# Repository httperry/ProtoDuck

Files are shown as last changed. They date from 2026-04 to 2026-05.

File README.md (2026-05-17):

# ProtoDuck





ProtoDuck is a general use microcontroller designed by combining two separate chips (`RP2350B` & `ESP32-C6`) to provide the maximum potential to the microcontroller. The board was designed to solve these problems faced by other microcontrollers in the market:
1. Little to no circuit protection (Try accidentally touching a few pins using jumper wires0
2. Less GPIO pins (For ___some___ use cases)
3. Less wireless connectivity
4. Lack of libraries in software

The aim of ProtoDuck is to provide a safe baseline for tinkerers to be able to safely continue their journey in hardware

Please note that this is the first PCB I ever designed and may contain many flaws, you are free to point them out via the issues section and if possible I will try fixing them!

## Board Visuals

**3D Visualisation Front**

Screenshot 2026-05-04 at 10 08 20 PM

**3D Visualisation Back**

Screenshot 2026-05-17 at 11 40 32 AM

**Schematic Drawing**

Schematic_ProtoDuck_v1_2026-05-04

**Top Layer PCB**

Screenshot 2026-05-17 at 11 20 19 AM

**Bottom Layer PCB**

Screenshot 2026-05-17 at 11 20 46 AM

**Middle Layer PCB**

Screenshot 2026-05-17 at 11 21 07 AM

## System Architechture

The ProtoDuck runs on a dual-microcontroller setup to prevent bottlenecking:

* **Primary Chip (RP2350B):** The main brain. Handles PC communication, GPIO pins, and runs user code. One ARM core is dedicated purely to system tasks and ESP communication, while the remaining cores are fully available for user code.
* **Wireless Co-Processor (ESP32-C6):** Connected via RX/TX. Exclusively handles WiFi (2.4GHz), Bluetooth 5+, and Zigbee. A custom HAL is being developed so users can access wireless features without eating into their own processing overhead.

## Power & Protection

The power circuit is designed while keeping the MCUs in mind to prevent any load on them. It features a `CH224K` chip for proper USB Type-C power negotiation, an `SRV05-4-P-T7` TVS Diode to absorb static shocks on data lines, and a `TPS54302DDCR_C311983` Step-Down Converter to cleanly drop the negotiated voltage to a stable 3.3V.

> [!NOTE]  
> **Hardware eFuse (`TPS259271DRCR`)**
> The board features an eFuse that automatically trips upon overloading or overdrawing. When tripped, a bright LED illuminates and power is cut off from the rest of the board. To clear the fault, you must physically unplug and replug the cable.

## Data Storage

To maximize security and prevent corruption, memory is isolated into three separate 128Mbit Flash chips (`GD25Q128ESIGR`), alongside the ESP32-C6's internal flash:

1. **`USR_FC` (User Chip):** Stores user code. Lowest priority at boot. Only accessible via PC/GUI for updates.
2. **`RP_FC` (Firmware Chip):** Stores the bootloader, kernel, and HALs. Connected via QSPI to the RP2350B. Uses an A/B partition system (similar to Android OTA updates) for safe flashing.
3. **`BC_FC` (Backup Chip):** Contains compressed firmware and an emergency bootloader for both MCUs in case of total system corruption.

There are physical pins on board that allow the user to flash the chips in case of recovery

## Pinout & Peripherals

The board maximizes usable IO and includes onboard peripherals (Reset Button, User Flash Button, System Status LED, Buzzer) for quick testing.
| Type | Count | Pins | Details |
|---|---|---|---|
| **Digital** | 21 | `D0`-`D20` | Programmable for PWM, I2C, SPI, etc. |
| **Analog** | 8 | `A0`-`A7` | Standard ADC inputs |
| **VBUS Protected** | 3 | `VBUS_PROT` | Safely routed from USB |
| **3.3V Power** | 5 | `+3.3V` | Regulated output |
| **GND** | 9 | `GND` | System ground |
| **I2C Header** | 1 | `I2C` | Dedicated plug-and-play header for displays |
| **Debug Header** | 1 | Labeled on Board | SWCLK & SWDIO |

## Emergency Recovery

If the software fails completely, ProtoDuck has physical hardware pins dedicated to recovering the board. Shorting these 1x1 male pin headers to `GND` triggers the following:

> [!IMPORTANT]  
> **`SYS-R` (System Restore)**
> Automatically fetches the compressed firmware from the `BC_FC` backup chip and safely reflashes the primary `RP_FC` chip.

> [!CAUTION]  
> **`FW-FLS` (Firmware Flash)**
> The nuclear option. If `SYS-R` fails, shorting this pin forces the RP flash chip to mount as a mass storage device on your PC. You can then drag-and-drop the firmware files to manually recover.

## Project Files & Links

This project was built using EasyEDA. The `.json` project files are included in this repository. 

## Bill of Materials (BOM)
[BOM](https://raw.githubusercontent.com/httperry/ProtoDuck/refs/heads/main/BOM.csv)

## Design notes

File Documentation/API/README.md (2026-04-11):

# ProtoDuck API Reference

Welcome to the ProtoDuck API documentation. This reference covers every module available to user code running on the ProtoDuck microcontroller.

---

## Quick Start

```python
# Pins just work — no import needed
D1.write(HIGH)
A0.read()
bus = I2C(D3, D4)

# Import modules as you need them
from protoduck import wifi, led, buzzer

wifi.connect()
resp = wifi.get("https://api.example.com/data")
print(resp.json())

# Async main auto-runs — no boilerplate
async def main():
    while True:
        led.set(A0.map(0, 255), 0, 0)
        await asyncio.sleep_ms(100)
```

---

## Always-Available Globals

These are injected by `boot.py` automatically. **Never import them.**

| Name | Type | Description |
|---|---|---|
| `D0` – `D20` | Pin objects | Digital GPIO pins |
| `A0` – `A7` | Pin objects | Analog GPIO pins (ADC) |
| `HIGH` | `1` | Digital high (3.3V) |
| `LOW` | `0` | Digital low (0V) |
| `INPUT` | const | Pin direction: input |
| `OUTPUT` | const | Pin direction: output |
| `PULLUP` | const | Enable internal pull-up resistor |
| `PULLDOWN` | const | Enable internal pull-down resistor |
| `I2C()` | constructor | Create I2C bus |
| `SPI()` | constructor | Create SPI bus |
| `PWM()` | constructor | Create PWM output |
| `UART()` | constructor | Create UART port |
| `asyncio` | module | Pre-imported async library |

---

## Modules

Each module has its own detailed documentation page:

| Module | Import | Description |
|---|---|---|
| [GPIO](gpio.md) | *(no import needed)* | Pin I/O, ADC, I2C, SPI, PWM, UART |
| [WiFi](wifi.md) | `from protoduck import wifi` | WiFi connection, HTTP, WebSocket, MQTT, sockets, hotspot |
| [Bluetooth](bluetooth.md) | `from protoduck import bluetooth` | BLE scanning, connecting, advertising, GATT server |
| [Zigbee](zigbee.md) | `from protoduck import zigbee` | IEEE 802.15.4 mesh networking |
| [LED](led.md) | `from protoduck import led` | Onboard RGB status LED control |
| [Buzzer](buzzer.md) | `from protoduck import buzzer` | Onboard buzzer/tone control |
| [System](system.md) | `from protoduck import system` | Board info, memory, storage, reset |
| [Thread](thread.md) | `from protoduck import thread` | True parallel execution via FreeRTOS tasks |
| [PCH Bridge](pch.md) | `import pch` or `import pchost` | Run PC-side Python libraries from board code |

---

## Important Notes

- **Pin objects are true globals.** All pins (`D0`–`D20`, `A0`–`A7`), peripherals, and constants (`HIGH`, `LOW`, etc.) are natively available in your script's global scope. You never need to import them or use a prefix.
- **`async def main()` auto-runs.** If your script defines an async `main()` function, the system calls `asyncio.run(main())` for you automatically.
- **RST button = soft reset.** It restarts your Python code only. WiFi, BLE, and USB connections stay alive.
- **MicroPython ≠ CPython.** This is MicroPython 1.24+ (Python 3.4+ syntax). For full CPython libraries, use the `pch` bridge.

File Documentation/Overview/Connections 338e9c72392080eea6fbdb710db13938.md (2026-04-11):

# Connections

Date: April 5, 2026

# RP2350B Connections

| GPIO Pin | Pin | Component |
| --- | --- | --- |
| 0 | RXD0 | ESP32-C6 |
| 1 | TXD0 | ESP32-C6 |
| 2 | DI | LED2 - RGB System Status LED |
| 3 | D20 | User-exposed GPIO pin |
| 4 | SO(IO1) | USR_FC1 |
| 5 | CS# | USR_FC1 |
| 6 | SCLK | USR_FC1 |
| 7 | SI(IO0) | USR_FC1 |
| 8 | SO(IO1) | BC_FC3 |
| 9 | CS# | BC_FC3 |
| 10 | SCLK | BC_FC3 |
| 11 | SI(IO0) | BC_FC3 |
| 12 | D0 | User-exposed GPIO pin |
| 13 | D19 | User-exposed GPIO pin |
| 14 | PG | CH224K |
| 15 | D18 | User-exposed GPIO pin |
| 16 | D17 | User-exposed GPIO pin |
| 17 | IO9 | ESP32-C6 |
| 18 | D16 | User-exposed GPIO pin |
| 19 | USR_FLS | Tactile Switch |
| 20 | EN | ESP32-C6 |
| 21 | SYS_R | System Restore Pin Header |
| 22 | D1 | User-exposed GPIO pin |
| 23 | D2 | User-exposed GPIO pin |
| 24 | D3 | User-exposed GPIO pin |
| 25 | D4 | User-exposed GPIO pin |
| 26 | D5 | User-exposed GPIO pin |
| 27 | D6 | User-exposed GPIO pin |
| 28 | D7 | User-exposed GPIO pin |
| 29 | D8 | User-exposed GPIO pin |
| 30 | D9 | User-exposed GPIO pin |
| 31 | D10 | User-exposed GPIO pin |
| 32 | D11 | User-exposed GPIO pin |
| 33 | D12 | User-exposed GPIO pin |
| 34 | D13 | User-exposed GPIO pin |
| 35 | D14 | User-exposed GPIO pin |
| 36 | D15 | User-exposed GPIO pin |
| 37 | 3 | CN1 [SM04B-SRSS-TB (LF)(SN)] - Display I2C header |
| 38 | 4 | CN1 [SM04B-SRSS-TB (LF)(SN)] - Display I2C header |
| 39 | - | Buzzer Control Via Transistor |
| 40_ADC0 | A7 | User-exposed Analog GPIO pin |
| 41_ADC1 | A6 | User-exposed Analog GPIO pin |
| 42_ADC2 | A5 | User-exposed Analog GPIO pin |
| 43_ADC3 | A4 | User-exposed Analog GPIO pin |
| 44_ADC4 | A3 | User-exposed Analog GPIO pin |
| 45_ADC5 | A2 | User-exposed Analog GPIO pin |
| 46_ADC6 | A1 | User-exposed Analog GPIO pin |
| 47_ADC7 | A0 | User-exposed Analog GPIO pin |
| QSPI_SS | FW_FLS | Firmware Flash Pin Header |
| QSPI_SS | CS# | RP_FC2 |
| QSPI_SD3 | HOLD#/RESET# (IO3) | RP_FC2 |
| QSPI_SD2 | WP# (IO2) | RP_FC2 |
| QSPI_SD1 | SO (IO1) | RP_FC2 |
| QSPI_SD0 | SI (IO0) | RP_FC2 |
| QSPI_SCLK | SCLK | RP_FC2 |

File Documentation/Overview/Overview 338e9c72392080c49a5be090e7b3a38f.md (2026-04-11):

# Overview

Date: April 4, 2026

ProtoDuck is a microcontroller designed from the ground up to overcome the many problems faced by tinkerers, makers, and builders who try their best to ideate and pour their heart into their hardware project for it to not work as expected or unknowingly damaging it.

It is created while keeping these problems in mind:

1. Complexity of Code Uploading and size issues with improper guidance to fix them
2. Accidentally Shorting the board and damaging it
3. Old hardware including most microcontrollers supporting a non-conventional USB input port
4. Lack of GPIO pins while working on big projects and relying on another microcontroller for more pins using RX and TX
5. Lack of firmware updates that could help improve their potential
6. And many more…

Basically what I’m indicating is that the current commonly available microcontrollers are not that great for basic prototyping, not great for people who are starting their journey to a new field.

---

# 1. Power and Protection

A microcontroller is a basic device that requires merely about 3.3V to stably work and sometimes even 1.1V! But there are other factors we need to account for while building the board, how will it be used? What things are going to be connected to it? How much power should be drawn?

For this we provide the user itself the option to choose how much power they want depending on their use case. We have provided a 2x3 pin header on which the user can connect a jumper connector to select their output, we are not stepping up the voltage on board but utilizing the sheer power of the source provided to us, we communicate with the power source for the selected power if available then we pass it through more safety measures and expose it via 3 female headers on board marked as `VBUS_PROT` 

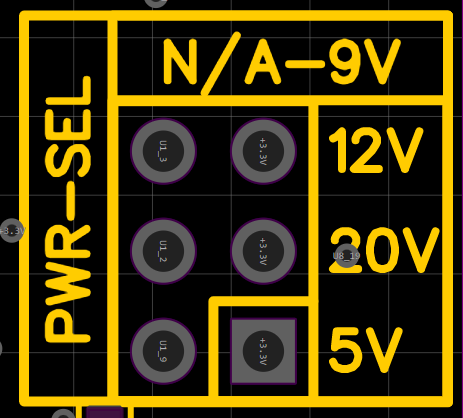
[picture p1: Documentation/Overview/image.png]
Power selection headers


Power selection headers

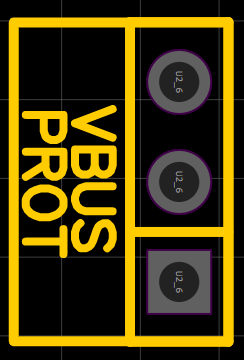
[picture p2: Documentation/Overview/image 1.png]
Requested power output


Requested power output

## 1.1 Static Charge Protection

A major cause of boards getting fried are static charges that the user unknowingly provides to the board, to prevent it we have added a small TVS diode that absorbs any static charges

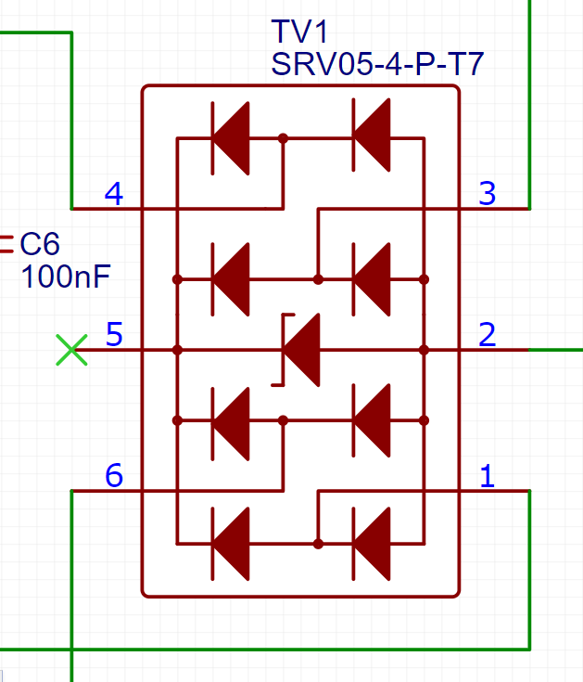
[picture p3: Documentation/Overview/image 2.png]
Schematic Diagram of TVS Diode


Schematic Diagram of TVS Diode

## 1.2 Overload Protection

There may be times the user may attach a motor to a 3.3V pin and draw too much power resulting in overheating of the board and eventually the board is dead. The `TPS259271DRCR` chip from Texas Instruments acts as an eFuse and gets tripped when too much power is drawn, it acts as the major protection feature of the board, after it gets tripped a `Red` colored LED turns on and the buzzer beeps indicating to the user that something went wrong and cuts off the power to the microcontrollers, this stays like this until the user unplugs and replugs the board indicating that the user has properly acknowledged the issue and fixed it

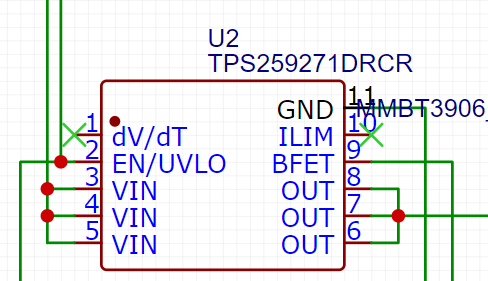
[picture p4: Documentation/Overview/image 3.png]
Schematic Diagram of eFuse Chip


Schematic Diagram of eFuse Chip

## 1.3 Power Step Down

The whole board majorly works on a steady 3.3V power instead of the *standardly assumed 5V* so the power needs to be stepped down this is where the role of `TPS54302DDCR_C311983`  chip by Texas instruments comes to play and steps down the voltage to a sweet 3.3V

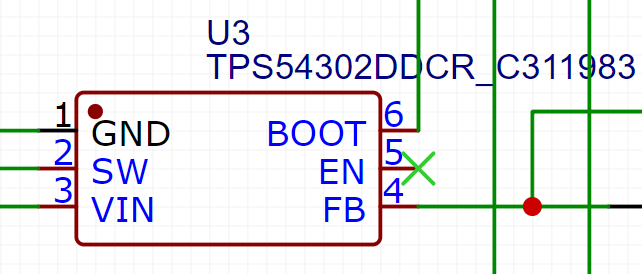
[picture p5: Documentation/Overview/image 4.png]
Schematic Diagram of Voltage Regulator


Schematic Diagram of Voltage Regulator

---

# 2. Computing and Wireless Communication

In the current age wireless communication systems have become an essential part of our lives including WiFi and Bluetooth. We have chosen the newly released `RP2350B` chip by Raspberry Pi Foundation which is a beast in terms of GPIO pins and computational power with an `ARM` based dual-core CPU, but this chip doesn’t have any means for wireless communication? Here I fell into a dilemma of whether to add my own WiFi and Bluetooth Chip (Adding additional burden) or try to find a package that has everything in it. To fix that we also added the newly released `ESP32-C6` chip that is a beast in wireless communication with Bluetooth, WiFi and Zigbee too! Both the chips communicate over their RX and TX lines

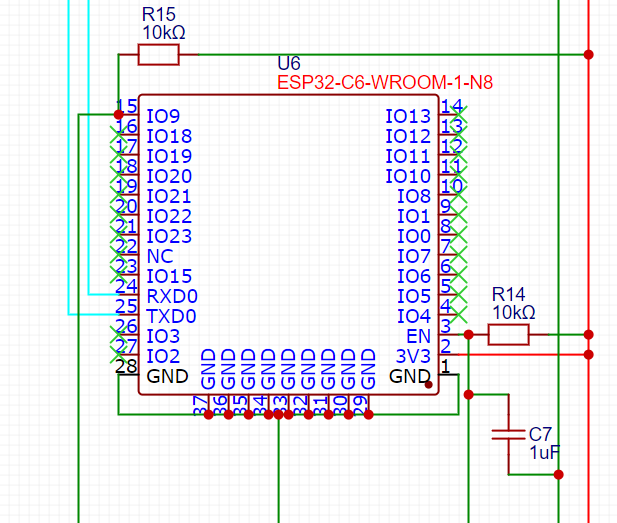
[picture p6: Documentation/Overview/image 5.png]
ESP32-C6 Schematic Diagram


ESP32-C6 Schematic Diagram

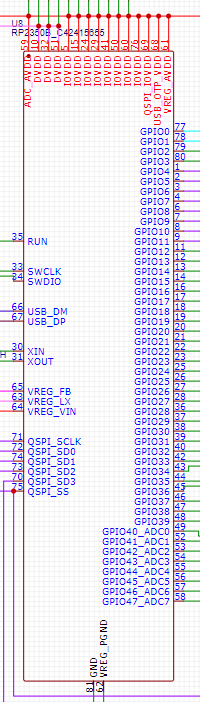
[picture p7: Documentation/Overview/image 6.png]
RP2350B Schematic Diagram


RP2350B Schematic Diagram

I will be developing a Hardware Abstraction Layer that will run with a RTOS on the RP chip that extracts all the functions and classes from the ESP chip and exposes it to the user code without the need of importing additional libraries, both the RTOS and HAL will consume one core of the ARM chips on both the chips and each chip has been reserved functions and they are independent systems that work in harmony

---

# 3. Storage and Backup

This stage threw me into a puzzle of how many Flash Memory Chips do I need to add on board? The goals that I was trying to achieve was:

1. Separation of the user code from the system code
2. Backup of the firmware of both systems in case of failure

I finally landed on a 3 chip architecture:

1. `USR_FC1` : This contains all the code uploaded by the user
2. `RP_FC2` : This contains the firmware for the RP chip and is properly partitioned to be an A/B partitioned system for updating and proper functioning
3. `BC_FC2` : This contains firmware of both the chips compressed into 2 different partitions

<aside>
💡

Note: All the chips are of 128Mbit

</aside>

This architecture opens many doors for OTA updates and firmware flashing and recovery

---

# 4. Interactive Elements

After adding all the major things on board, I needed to visualize how the board would look and how I envision it to be. After careful consideration, I decided to follow this:

| Type | No. of Pins | Function |
| --- | --- | --- |
| Digital Pins (Programmable) (Female) | 21 | Can be used as regular digital pins or as I2C or anything else! There are endless possibilities! |
| Analog Pins (Female) | 8 | Read analog inputs |
| I2C Header (Female) | 1 | Plug n Play enabling the board for attaching a display or something else |
| Buzzer | 1 | Notification to the user or an asset to the user reducing the need for a speaker or tweeter |
| RGB LED | 1  | To indicate the system status to the user |
| Serial Debugging Headers (Male) | 1 | Debugging and seeing what is causing the error on chip (Advanced debugging) |
| `RST` Tactile Switch | 1 | To reset the board |
| `USR_FLS` Tactile Switch | 1 | To expose the user flash chip to the user PC as a virtual drive |
| Power Selection Headers (Male) | 1 | To select the required power |
| Red LED (Fault Indicator) | 1 | To indicate any power fault |

---

# 5. Project Vision

I envision the microcontroller to be properly controllable by the PC and ease of use, for that I will build a WinUI3 & C# powered app that will control and handle all the major things like board drivers and firmware updates and also the user will be able to beautifully see the reading on the board without the need of adding print statements and finding the reading in the output, over the app the user will also be able to flash their custom firmware that they can develop and flash but a warning will be shown to warn the user about the potential risks and also the user will also be able to reflash the entire board using the official firmware or recover the board using the backup chips all over the app and the user can upload their code over the app and monitor it beautifully, it will show live updates of device metrics and storage information along with sensor information.

I also plan to create an additional library for the user code that will allow the board to share its computational power load to the connected PC for more powerful computation. This will open endless possibilities that will only be limited by the user’s imagination!

Also this project is going to be open source, so it will be properly maintained and bugs will be near zero! I hope for the future developers to keep this sprit going on!

Adios!

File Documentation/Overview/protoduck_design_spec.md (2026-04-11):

# ProtoDuck — Complete Design Specification

> **Status:** All major decisions locked ✅  
> **Last Updated:** April 5, 2026

---

## Hardware Overview

ProtoDuck is a dual-chip microcontroller designed for makers, tinkerers, and educators,
featuring robust protection, wireless connectivity, and a Python-first developer experience.

### Chips

| Chip | Role |
|---|---|
| **RP2350B** | Major chip — GPIO, USB, PC communication, user code runtime |
| **ESP32-C6-WROOM-1-N8** | Wireless chip — WiFi 6, BT 5.3, Zigbee, OTA downloader |

### Flash Storage (Three-Chip Architecture)

| Chip | Size | Format | Purpose |
|---|---|---|---|
| **USR_FC1** | 128Mbit (16MB) | FAT32 | 100% user space — `.py` files, `/lib/`, data |
| **RP_FC2** | 128Mbit (16MB) | A/B Partitioned | RP firmware, FreeRTOS, HAL, MicroPython |
| **BC_FC3** | 128Mbit (16MB) | FAT32 (2 partitions) | Factory backup only — compressed RP + ESP firmware |

> **No microSD card slot.** Users manage within the 16MB USR_FC1 budget.  
> **BC_FC3 is written ONCE during manufacturing. Never written to again.**

### RP_FC2 Layout

```
RP_FC2 (16MB)
├── Metadata Region (256KB)
│   ├── Active partition flag (A or B)
│   ├── Boot attempt counter (0–3, rollback trigger)
│   ├── confirmed flag (true after 3 clean boots)
│   ├── Firmware version strings
│   └── SHA256 hashes of both partitions
│
├── Partition A — Active (7.8MB)
│   ├── Stage 2 Bootloader      [~64KB]
│   ├── FreeRTOS Kernel          [~256KB]
│   ├── HAL + TrustZone setup    [~512KB]
│   └── MicroPython firmware     [~1.5MB]
│
└── Partition B — OTA Target (7.8MB)
    └── (identical structure, written via chunked OTA)
```

### BC_FC3 Layout

```
BC_FC3 (16MB, FAT32)
├── Partition 1: /rp_firmware.bin.gz   (compressed RP full firmware)
└── Partition 2: /esp_firmware.bin.gz  (compressed ESP full firmware)
```

---

## Power System

| Component | Role |
|---|---|
| **CH224K** | USB-PD negotiation — user selects 5V / 9V / 12V / 20V via PWR-SEL jumper header |
| **TPS259271DRCR** | eFuse — overcurrent protection, trips and cuts power, Red LED + Buzzer alert |
| **TPS54302DDCR** | Buck regulator — steps down to stable 3.3V for board operation |
| **SRV05-4-P-T7** | TVS Diode — ESD/static charge absorption |

**Fault behaviour:** eFuse trips → Red LED on + Buzzer beeps → power cut to chips → stays latched until USB unplug/replug (user acknowledges and fixes fault).

---

## Connections (RP2350B GPIO Map)

| GPIO | Pin Label | Connected To |
|---|---|---|
| 0 | RXD0 | ESP32-C6 (UART RX) |
| 1 | TXD0 | ESP32-C6 (UART TX) |
| 2 | DI | LED2 — RGB System Status LED |
| 3 | D20 | User GPIO |
| 4–7 | SPI | USR_FC1 (SO, CS#, SCLK, SI) |
| 8–11 | SPI | BC_FC3 (SO, CS#, SCLK, SI) |
| 12–13 | D0, D19 | User GPIO |
| 14 | PG | CH224K (power good) |
| 15–16, 18 | D18, D17, D16 | User GPIO |
| 17 | IO9 | ESP32-C6 control |
| 19 | USR_FLS | Tactile switch (3-sec hold = mount USR_FC1 as USB drive) |
| 20 | EN | ESP32-C6 enable |
| 21 | SYS_R | System Restore header |
| 22–36 | D1–D15 | User GPIO |
| 37–38 | SCL, SDA | CN1 — Display I2C header |
| 39 | — | Buzzer (via transistor) |
| 40–47 | A0–A7 | User Analog GPIO (ADC) |
| QSPI_SS | FW_FLS | Firmware flash pin header (RP_FC2 recovery) |
| QSPI_SS–SCLK | — | RP_FC2 (native QSPI boot interface) |

---

## Computing Architecture

### RP2350B Core Split

```
Core 0 — FreeRTOS [TrustZone SECURE world]
├── HAL (GPIO, SPI, UART, ADC drivers)
├── Flash manager (USR_FC1 r/w, BC_FC3 read, RP_FC2 OTA writer)
├── USB manager (CDC ↔ Mass Storage mode switching)
├── OTA engine (chunk receiver, hash verifier, metadata updater)
├── pch bridge server (deserialize calls → execute → serialize response)
└── ESP32 UART protocol handler (full-duplex async)

Core 1 — MicroPython [TrustZone NON-SECURE world]
├── Runs user code: boot.py (locked) → main.py (user entry point)
├── protoduck.* built-in namespace
├── pch / pchost module (PC bridge)
└── asyncio event loop
```

> **TrustZone enforcement:** ARM SAU/MPU memory-level. Non-Secure world (Core 1) cannot
> directly access flash drivers, UART to ESP, or RP_FC2. All hardware access goes through
> validated secure veneer function calls.

### ESP32-C6 Core Split

```
Core 0 — FreeRTOS (isolated)
├── Wireless stack (WiFi 6, BT 5.3, Zigbee/Thread 802.15.4)
├── HAL communicator (full-duplex UART binary protocol with RP2350B)
└── OTA downloader (HTTP range requests → chunk → UART → RP)

Core 1 — User wireless tasks (delegated from RP via protocol)
```

### ESP32-C6 Internal Flash Layout (8MB)

```
├── Bootloader              [64KB]
├── Partition Table         [4KB]
├── FreeRTOS App (OTA A)    [~3MB]  — current firmware
├── FreeRTOS App (OTA B)    [~3MB]  — ESP OTA target slot
├── NVS (encrypted)         [512KB] — WiFi credentials (AES-256 via ESP flash encryption)
└── OTA Data                [8KB]   — active slot tracking
```

---

## RP ↔ ESP Communication Protocol

- **Physical:** UART full-duplex async (GPIO 0/1 on RP, RXD0/TXD0 on ESP)
- **Control lines:** RP GPIO17 → ESP IO9, RP GPIO20 → ESP EN
- **Frame format:** Length-prefixed binary packets with command IDs
- **Direction:** Both chips can initiate — RP sends commands, ESP sends async events (WiFi connected, OTA chunk ready, etc.)

---

## User Python Environment

### MicroPython

- **Version:** MicroPython 1.23+ (RP2350 supported)
- **Location:** Bundled inside RP_FC2 A/B partitions (system-managed, not user-replaceable)
- **User entry point:** `main.py` on USR_FC1
- **System entry:** `boot.py` on USR_FC1 — **system-locked, not user-editable**
  - Initialises HAL session, pch bridge, mounts USR_FC1 filesystem
  - Adds `/lib` to `sys.path`

### File Layout on USR_FC1

```
USR_FC1 (16MB FAT32) — mounted as root /
├── boot.py      ← LOCKED — system-generated, not editable by user
├── main.py      ← User entry point
├── config.py    ← User config (optional)
├── mymodule.py  ← User modules
└── lib/         ← User libraries (installed via Library Manager or copied)
    └── mylib/
```

### ProtoDuck Module Namespace

All HAL features exposed via explicit imports:

```python
from protoduck import gpio
from protoduck import wireless
from protoduck import display
from protoduck import storage
from protoduck import system
```

User code cannot directly touch hardware — all calls go through TrustZone veneer functions.

---

## PC Host Bridge (`pch` / `pchost`)

### Purpose

Allows user code on the board to execute computationally heavy Python libraries
(numpy, pandas, matplotlib, etc.) on the connected PC's full CPython 3.12 instance.
Both `pch` and `pchost` are identical aliases to the same module.

### Import Syntax

```python
from pch import numpy as np          # explicit PC import
from pchost import pandas as pd      # identical, long-form alias
```

Regular MicroPython imports are unchanged — `pch`/`pchost` prefix is the explicit signal.

### Per-Call Timeout

```python
pch.timeout = 5.0  # global default (seconds)

# Per-call override using __timeout keyword
result = np.fft.fft(large_array, __timeout=30.0)
```

`__timeout` is intercepted by the pch proxy — never forwarded to the actual library.

### Exception Hierarchy

```
PCHError
├── PCHNotConnectedError    — USB not physically connected / app not running
├── PCHImportError          — library not found in PC venv
├── PCHTimeoutError         — no response within timeout window
├── PCHDisconnectedError    — USB dropped mid-computation
└── PCHSerializationError   — data couldn't be serialized for transfer
```

### Graceful Fallback Pattern

```python
try:
    from pch import numpy as np
except (PCHNotConnectedError, PCHImportError):
    import ulab.numpy as np  # on-board fallback
```

### PC App Python Runtime

- **Bundled CPython 3.12** shipped inside WinUI3 app install — no user Python install needed
- **Isolated venv** at `<AppInstall>/python/venv/` — zero conflict with user's system Python
- Library Manager UI = `pip install` into this venv
- `matplotlib` renders to WinUI3 app Visualization panel, not a desktop window

### Auto-Reconnection

- PC app always runs as a **Windows background service** (system tray)
- On USB disconnect: `PCHDisconnectedError` raised, HAL silently polls every 500ms
- On USB reconnect: session re-established automatically, `@pch.on_reconnect` callback fires
- No user action required

---

## Recovery System

### Path 1: SYS_R (Hardware or Software Triggered)

```
SYS_R pin triggered OR software command from app
    ▼
RP2350B bootloader mode
    1. Mount BC_FC3 over SPI
    2. Read /rp_firmware.bin.gz
    3. Decompress (streaming — no full RAM needed)
    4. Write to ACTIVE A/B partition
    5. Reboot
```

### Path 2: FW_FLS Header (Manual Brick Recovery)

```
Board enters USB Mass Storage mode — exposes RP_FC2 as "PROTODUCK_FW" drive
    ▼
User drops official .uf2 file
    ▼
Bootloader detects .uf2 → flashes to inactive partition → reboots
```

### USR_FLS Button (3-Second Hold)

Mounts USR_FC1 as USB Mass Storage drive ("PROTODUCK_USR") on connected PC.
User can drag-drop `.py` files, `/lib/` contents, etc. directly.
Single press / less than 3 seconds = ignored.

---

## OTA Update System

### Update Check
- ESP32-C6 background task checks update server every 24h or on WiFi connect
- Update server: GitHub Releases API (or custom CDN — TBD)

### Download & Install Flow

```
1. Update detected → ESP notifies RP → RP notifies PC app via USB

2. PC app shows actionable notification:
   "Firmware v1.2 available — [Release Notes] [Download & Install] [Later]"

3. User clicks [Download & Install]
   → PC signals board → ESP32 begins HTTP range requests in chunks
   → Each chunk: ESP → UART → RP → written to INACTIVE A/B partition
   → PC app shows live progress bar

4. All chunks received → SHA256 verified against server hash
   ├── Corrupt → partition abandoned, notify "Download failed, try again"
   └── Verified → metadata written:
       next_boot = INACTIVE, boot_attempts = 0, confirmed = FALSE

5. PC app shows: "Update ready! [Restart Now] [Later]"
   User clicks [Restart Now] → board reboots

6. Bootloader boots INACTIVE partition
   FreeRTOS health check:
   ├── Pass × 3 boots → confirmed = TRUE, old partition becomes standby ✅
   └── Fail × 3 boots → auto-rollback to OLD partition ✅

7. Power loss DURING write:
   → Metadata never changed → board boots OLD partition ✅

8. Power loss AFTER metadata write, BEFORE confirm:
   → boot_attempts increments each attempt
   → After 3 failures → auto-rollback ✅
```

> **Nothing can brick the board through OTA. The old partition is always the safety net.**

---

## WinUI3 PC App — Feature List

| Panel | Features |
|---|---|
| **Code Editor** | Syntax-highlighted Python editor, multi-file support |
| **File Manager** | USR_FC1 filesystem browser, drag-drop upload/delete |
| **Serial Monitor** | Timestamped output, filtering, copy |
| **Live Python REPL** | Interactive shell on board over USB CDC |
| **GPIO Dashboard** | Live pin state visualization, toggle digital outputs |
| **Visualization** | `pch matplotlib` renders here, live sensor graphs |
| **Library Manager** | Search + one-click install into bundled CPython venv |
| **Firmware Manager** | OTA notifications + progress, A/B swap, BC_FC3 recovery trigger |
| **Device Metrics** | Storage usage (USR_FC1 bar), CPU load, RAM usage, uptime |
| **WiFi Config** | SSID/password setup (written to ESP32 NVS, AES-256 encrypted) |

---

## Interactive Elements on Board

| Element | Count | Function |
|---|---|---|
| Digital GPIO (Female) | 21 | Programmable — digital, I2C, SPI, PWM, etc. |
| Analog GPIO (Female) | 8 | ADC input (A0–A7) |
| I2C Display Header | 1 | Plug-and-play display or other I2C device |
| Buzzer | 1 | User-accessible + system fault alert |
| RGB LED | 1 | System status indicator |
| Red LED | 1 | Power fault indicator (eFuse tripped) |
| Serial Debug Header | 1 | Advanced SWD/UART debugging |
| RST Tactile Switch | 1 | Board reset |
| USR_FLS Tactile Switch | 1 | 3-sec hold = mount USR_FC1 as USB drive |
| PWR-SEL Header (Male) | 1 | Jumper to select 5/9/12/20V output |
| VBUS_PROT Headers (Female) | 3 | Protected voltage output to user |
| SYS_R Pin Header | 1 | System restore trigger |
| FW_FLS Pin Header | 1 | Exposes RP_FC2 for manual firmware recovery |

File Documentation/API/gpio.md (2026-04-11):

# GPIO

Welcome to the magic of ProtoDuck's hardware API. We've eliminated the boilerplate so you can focus on building. All pins, peripheral constructors, and constants are seamlessly injected into your script's environment automatically—**no import statements required.**

```python
# Beautifully clean hardware control directly out of the box
D1.write(HIGH)
A0.read()
```

---

## Constants

Always available globally:

| Name | Description |
|---|---|
| `HIGH` | Digital high (3.3V) |
| `LOW` | Digital low (0V) |
| `INPUT` | Pin direction: input |
| `OUTPUT` | Pin direction: output |
| `PULLUP` | Internal pull-up resistor |
| `PULLDOWN` | Internal pull-down resistor |

---

## Digital Pins

Available: `D0` – `D20` (21 pins)

### Writing & Reading

```python
D1.write(HIGH)
D1.write(LOW)
D1.toggle()

state = D1.read()       # 0 or 1
```

### Pin Mode

```python
D1.mode(INPUT)
D1.mode(INPUT, PULLUP)
D1.mode(INPUT, PULLDOWN)
D1.mode(OUTPUT)
```

> Mode is auto-detected from first use — `write()` sets OUTPUT, `read()` sets INPUT. Only call `.mode()` if you need pull resistors.

---

## Events

All support **decorator syntax**.

### `@Dn.on_high`

Fires when pin goes HIGH (rising edge).

```python
@D1.on_high
def pressed():
    led.set_color("green")
```

### `@Dn.on_low`

Fires when pin goes LOW (falling edge).

```python
@D1.on_low
def released():
    led.off()
```

### `@Dn.on_click`

Fires after a complete press-release cycle (HIGH → LOW → HIGH, or LOW → HIGH → LOW depending on wiring). This is the "button was clicked" event.

```python
@D1.on_click
def clicked():
    buzzer.beep()
    D9.toggle()
```

Optional debounce (default 50ms):
```python
@D1.on_click(debounce=100)
def clicked():
    print("Clicked!")
```

### `@Dn.on_change`

Fires on any state change.

```python
@D5.on_change
def motion():
    print("Motion detected!")
```

### Aliases

For users familiar with electrical terms:
- `on_rise` = `on_high`
- `on_fall` = `on_low`

---

## Analog Pins

Available: `A0` – `A7` (8 pins, 12-bit ADC)

### Reading

```python
A0.read()           # raw int, 0–4095
A0.read(10)         # average of 10 readings

A0.readvolt()       # float voltage, 0.0–3.3
A0.readvolt(10)     # average of 10 voltage readings
```

> **Pro Tip:** Need to smooth out a noisy sensor? Simply pass the number of samples to instantly get a clean, hardware-averaged reading!

### Mapping

The `map()` function provides a quick, mathematical conversion of the current reading into your desired range. It returns a snapshot of the value right now.

```python
A0.map(0, 100)        # 0–4095 → 0–100 (percentage)
A0.map(0, 180)        # for a servo angle
A0.map(0.0, 3.3)      # same as readvolt()
A0.map(0, 255)        # for LED brightness

# Use it directly
out.duty(A0.map(0, 100))
```

### Streaming (Live Value)

`stream()` starts background sampling and returns a **live value** that always holds the latest reading. Just use it like a variable.

```python
live = A0.stream()          # raw value, updates in background
print(live)                 # 2048
print(live)                 # 2051 (newer reading)

live = A0.stream(0, 100)    # mapped live value (0–100)
print(live)                 # 50
print(live)                 # 51

live.stop()                 # stop background sampling
```

Customize sample rate:

```python
live = A0.stream(rate=200)         # 200 samples/sec (default: 100)
live = A0.stream(0, 100, rate=50)  # mapped, 50 samples/sec
```

---

## Peripherals

Global constructors — no pin method chaining needed.

### I2C

```python
bus = I2C(D3, D4)                 # SDA, SCL
bus = I2C(D3, D4, freq=400000)    # with custom frequency
```

**Methods:**

```python
bus.scan()                         # → [0x3C, 0x48, ...]
bus.writeto(0x3C, b'\x00\x01')
bus.readfrom(0x3C, 4)
bus.write_reg(0x3C, 0xAC, b'\x33')
bus.read_reg(0x3C, 0x00, 6)
bus.release()                      # free pins back to GPIO
```

**Device handle** (for cleaner multi-device code):

```python
bus = I2C(D3, D4)
sensor = bus.device(0x38)
display = bus.device(0x3C)

sensor.write_reg(0xAC, b'\x33\x00')
data = sensor.read_reg(0x00, 6)

display.writeto(b'\x00\x10\xFF')
```

**Context manager** (auto-releases pins when done):

```python
with I2C(D3, D4) as bus:
    bus.writeto(0x3C, b'\x00')
# D3 and D4 are free again
```

### SPI

```python
bus = SPI(D5, D6, D7, D8)         # CS, SCK, MOSI, MISO
bus = SPI(D5, D6, D7)             # CS, SCK, MOSI (no MISO, write-only)
```

**Methods:**

```python
bus.write(b'\x01\x02')
bus.read(4)
bus.transfer(out, inp)             # full duplex
bus.release()
```

### PWM

```python
out = PWM(D9)                      # default: 1kHz, 50% duty
out = PWM(D9, freq=500, duty=25)
```

**Methods:**

```python
out.duty(75)          # change duty %
out.freq(1000)        # change frequency
out.stop()            # stop, pin goes LOW
```

### UART

```python
port = UART(D10, D11)              # RX, TX
port = UART(D10, D11, baud=9600)   # custom baud rate
```

**Methods:**

```python
port.write(b"hello")
port.read(64)
port.readline()
port.any()              # bytes in buffer
port.release()
```

### Pin Locking

Once a pin is used in a peripheral, it's locked:

```python
bus = I2C(D3, D4)
D3.write(HIGH)       # ❌ PinModeError: D3 is in use as I2C SDA

bus.release()
D3.write(HIGH)       # ✅ works now
```

---

## Exceptions

| Exception | When |
|---|---|
| `PinModeError` | Using `write()`/`read()` on a pin locked to a peripheral |
| `PinConflictError` | Pin already assigned to another peripheral |
| `PinReleasedError` | Using a bus object after it was released |
| `ADCError` | Calling `.read()`/`.readvolt()` on a non-ADC digital pin |

---

## Full Example

```python
from protoduck import wifi, led, buzzer

# Hardware objects are ready to go natively!

@D1.on_click
def button():
    buzzer.beep()
    resp = wifi.get("https://api.example.com/data")
    print(resp.json())

live = A0.stream(0, 100)    # live percentage

bus = I2C(D3, D4)
sensor = bus.device(0x48)

async def main():
    while True:
        led.set(int(live * 2.55), 0, 0)    # brightness from A0
        temp = sensor.read_reg(0x00, 2)
        print(f"Light: {live}%  Temp: {temp}")
        await asyncio.sleep(1)
```

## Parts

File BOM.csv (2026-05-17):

ID | Name | Designator | Footprint | Quantity | Manufacturer Part | Manufacturer | Supplier | Supplier Part | Price | Pins | Contributor | JLCPCB Part Class
1 | GD25Q128ESIGR | BC-FC3,RP-FC2,USR-FC1 | SOP-8_L5.3-W5.3-P1.27-LS8.0-BL | 3 | GD25Q128ESIGR | GigaDevice(兆易创新) | LCSC | C2928891 |  | 8 | LCSC | Extended Part
2 | 2700Hz | BUZZER1 | BUZ-SMD_4P-L8.5-W8.5-P8.50-TL | 1 | MLT-8540H | 华能 | LCSC | C95298 |  | 4 |  | Extended Part
3 | 10uF | C1,C2,C8 | C1206 | 3 | CL31A106KBHNNNE | SAMSUNG(三星) | LCSC | C13585 |  | 2 |  | Basic Part
4 | 100nF | C3 | C0603 | 1 | CC0603KRX7R9BB104 | YAGEO(国巨) | LCSC | C14663 |  | 2 |  | Basic Part
5 | 22uF | C4,C5 | C0805 | 2 | CL21A226MOQNNNE | SAMSUNG(三星) | LCSC | C98190 |  | 2 |  | Extended Part
6 | 100nF | C6 | C0402 | 1 | CL05B104KB54PNC | SAMSUNG(三星) | LCSC | C307331 |  | 2 | LCSC | Basic Part
7 | 1uF | C7 | C0603 | 1 | CL10B105KB8NQNC | SAMSUNG(三星) | LCSC | C5199872 |  | 2 | lcsc | Extended Part
8 | 100nF | C9,C10,C11,C12,C13,C14,C15,C16,C17,C18,C19,C20,C21,C22,C23 | C0402 | 15 | CL05B104KO5NNNC | SAMSUNG(三星) | LCSC | C1525 |  | 2 |  | Basic Part
9 | 10uF | C28 | C0402 | 1 | CL05A106MQ5NUNC | SAMSUNG(三星) | LCSC | C15525 |  | 2 |  | Basic Part
10 | SM04B-SRSS-TB (LF)(SN) | CN1 | CONN-SMD_4P-P1.00_SM04B-SRSS-TB-LF-SN | 1 | SM04B-SRSS-TB(LF)(SN) | JST | LCSC | C160404 |  | 6 | LCSC | Extended Part
11 | HX PM2.54-1X9P ZC-Y | CN2 | HDR-TH_9P-P2.54-V-F-1 | 1 | HX PM2.54-1x9P ZC-Y | hanxia(韩下) | LCSC | C22438159 |  | 9 | lcsc | Extended Part
12 | SMAJ22A_C51045908 | D1 | DO-214AC_L4.3-W2.7-LS5.3-RD | 1 | SMAJ22A | Brightking(君耀电子) | LCSC | C51045908 |  | 2 | lcsc | Extended Part
13 | 1N4148_C18195411 | D2 | DO-35_BD2.2-L4.0-D0.50_1N4148 | 1 | 1N4148 | LJ(朗捷) | LCSC | C18195411 |  | 2 | lcsc | Extended Part
14 | JK-MSMD050-30 | F1 | F1812 | 1 | JK-MSMD050-30 | JK(金科) | LCSC | C369168 |  | 2 | LCSC | Extended Part
15 | Header-Male-2.54_1x1 | FW-FLS,SYS-R | HDR-TH_1P-P2.54-V-M | 2 | 2.54-1*1P针 | BOOMELE(博穆精密) | LCSC | C81276 |  | 1 |  | Extended Part
16 | 2.54-2*3 | H1 | HDR-TH_6P-P2.54-V-R2-C3-S2.54_A2541WV-2X3P | 1 | 2.54-2*3 | ZHOURI(洲日) | LCSC | C5116479 |  | 6 | lcsc | Extended Part
17 | Header-Female-2.54_1x5 | H2 | HDR-TH_5P-P2.54-V-F | 1 | 2.54-1*5P母 | BOOMELE(博穆精密) | LCSC | C50950 |  | 5 |  | Extended Part
18 | Header-Male-2.54_1x3 | H3 | HDR-TH_3P-P2.54-V-M-1 | 1 | 2.54-1*3P针 | BOOMELE(博穆精密) | LCSC | C49257 |  | 3 |  | Extended Part
19 | 4.7uH | L1 | IND-SMD_L6.0-W6.0 | 1 | CKCS6045-4.7uH/M | CENKER(岑科) | LCSC | C5291878 |  | 2 | lcsc | Extended Part
20 | 3.3uH | L3 | IND-SMD_L2.0-W1.6_AOTA-B201610S3R3-101-T | 1 | AOTA-B201610S3R3-101-T | ABRACON | LCSC | C42411119 |  | 2 | lcsc | Extended Part
21 | 17-21VRD/TR8 | LED1 | LED0805-R-RD | 1 | 17-21VRD/TR8 | EVERLIGHT(亿光) | LCSC | C264415 |  | 2 | LCSC | Extended Part
22 | WS2812C-2020-V1 | LED2 | LED-SMD_4P-L2.0-W2.0-TL_WS2812B-2020 | 1 | WS2812C-2020-V1 | worldsemi | LCSC | C2976072 |  | 4 | lcsc | Extended Part
23 | Header-Female-2.54_1x16 | P3 | HDR-TH_16P-P2.54-V-F-1 | 1 | 2.54-1*16P母 | BOOMELE(博穆精密) | LCSC | C66987 |  | 16 |  | Extended Part
24 | Header-Female-2.54_1x3 | P4 | HDR-TH_3P-P2.54-V-F | 1 | 2.54-1*3P母 | BOOMELE(博穆精密) | LCSC | C146243 |  | 3 |  | Extended Part
25 | Header-Female-2.54_1x8 | P6 | HDR-TH_8P-P2.54-V-F | 1 | 2.54-1*8P母环保 | BOOMELE(博穆精密) | LCSC | C27438 |  | 8 |  | Extended Part
26 | MMBT3906_C51953475 | Q1 | SOT-23-3_L2.9-W1.3-P1.90-LS2.4-BR | 1 | MMBT3906 | CCX(晁禾) | LCSC | C51953475 |  | 3 | lcsc | Extended Part
27 | S8050_C51953468 | Q2 | SOT-23-3_L2.9-W1.3-P1.90-LS2.4-BR | 1 | S8050 | CCX(晁禾) | LCSC | C51953468 |  | 3 | lcsc | Extended Part
28 | 47kΩ | R1 | R0603 | 1 | 0603WAF4702T5E | UNI-ROYAL(厚声) | LCSC | C25819 |  | 2 |  | Basic Part
29 | 10kΩ | R2,R3,R10,R11,R12,R14,R15 | R0603 | 7 | FRC0603J103 TS | FOJAN(富捷) | LCSC | C2930027 |  | 2 | LCSC | Extended Part
30 | 33kΩ | R4 | R0603 | 1 | FRC0603F3302TS | FOJAN(富捷) | LCSC | C2907028 |  | 2 | lcsc | Extended Part
31 | 100kΩ | R5 | R0603 | 1 | FRC0603J104 TS | FOJAN(富捷) | LCSC | C2907088 |  | 2 | lcsc | Extended Part
32 | 22kΩ | R6 | R0402 | 1 | 0402WGF2202TCE | UNI-ROYAL(厚声) | LCSC | C25768 |  | 2 |  | Basic Part
33 | 20kΩ | R7 | R0603 | 1 | FRC0603F2002TS | FOJAN(富捷) | LCSC | C2907011 |  | 2 | lcsc | Extended Part
34 | 100kΩ | R8 | R0603 | 1 | FCR0603F100K | VO(翔胜) | LCSC | C5913165 |  | 2 | lcsc | Extended Part
35 | 1.5kΩ | R9 | R2512 | 1 | FRC2512F1501TS | FOJAN(富捷) | LCSC | C5153994 |  | 2 | lcsc | Extended Part
36 | 1kΩ | R13,R16,R17 | R0603 | 3 | 0603WAF1001T5E | UNI-ROYAL(厚声) | LCSC | C21190 |  | 2 |  | Basic Part
37 | TS665CJ | RST,USR-FLASH | SW-TH_4P-L6.0-W6.0-P4.50-LS6.5 | 2 | TS665CJ | SHOU HAN(首韩) | LCSC | C393938 |  | 4 | LCSC | Extended Part
38 | SRV05-4-P-T7 | TV1 | SOT-23-6_L2.9-W1.6-P0.95-LS2.8-BR | 1 | SRV05-4-P-T7 | PROTEK | LCSC | C85364 |  | 6 |  | Extended Part
39 | CH224K | U1 | ESSOP-10_L4.9-W3.9-P1.0-LS6.0-TL-EP | 1 | CH224K | WCH(南京沁恒) | LCSC | C970725 |  | 11 | lcsc | Extended Part
40 | TPS259271DRCR | U2 | VSON-10_L3.0-W3.0-P0.50-TL-EP | 1 | TPS259271DRCR | TI(德州仪器) | LCSC | C2653851 |  | 11 | lcsc | Extended Part
41 | TPS54302DDCR_C311983 | U3 | SOT-23-6_L2.9-W1.6-P0.95-LS2.8-BL | 1 | TPS54302DDCR | TI(德州仪器) | LCSC | C311983 |  | 6 | LCSC | Extended Part
42 | ESP32-C6-WROOM-1-N8 | U6 | WIRELM-SMD_ESP32-C6-WROOM-1 | 1 | ESP32-C6-WROOM-1-N8 | ESPRESSIF(乐鑫) | LCSC | C5366877 |  | 37 | lcsc | Extended Part
43 | RP2350B_C42415655 | U8 | QFN-80_L10.0-W10.0-P0.40-TL-EP3.4 | 1 | RP2350B | Raspberry Pi(树莓派) | LCSC | C42415655 |  | 81 | lcsc | Extended Part
44 | BX-PM2.54-1-5PY | U9 | HDR-TH_5P-P2.54-V-F-B | 1 | BX-PM2.54-1-5PY | Bossie(博锡) | LCSC | C18078128 |  | 5 | lcsc | Extended Part
45 | TYPE-C-31-M-12 | USBC1 | USB-C_SMD-TYPE-C-31-M-12_1 | 1 | TYPE-C-31-M-12 | 韩国韩荣 | LCSC | C165948 |  | 16 | LCSC | Extended Part
46 | 12MHz | X1 | CRYSTAL-SMD_4P-L3.2-W2.5-BL | 1 | X322512MSB4SI | YXC(扬兴晶振) | LCSC | C9002 |  | 4 |  | Basic Part

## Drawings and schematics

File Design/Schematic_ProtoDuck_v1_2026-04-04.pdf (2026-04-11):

## +3.3V Bus

## VBUS_RAW

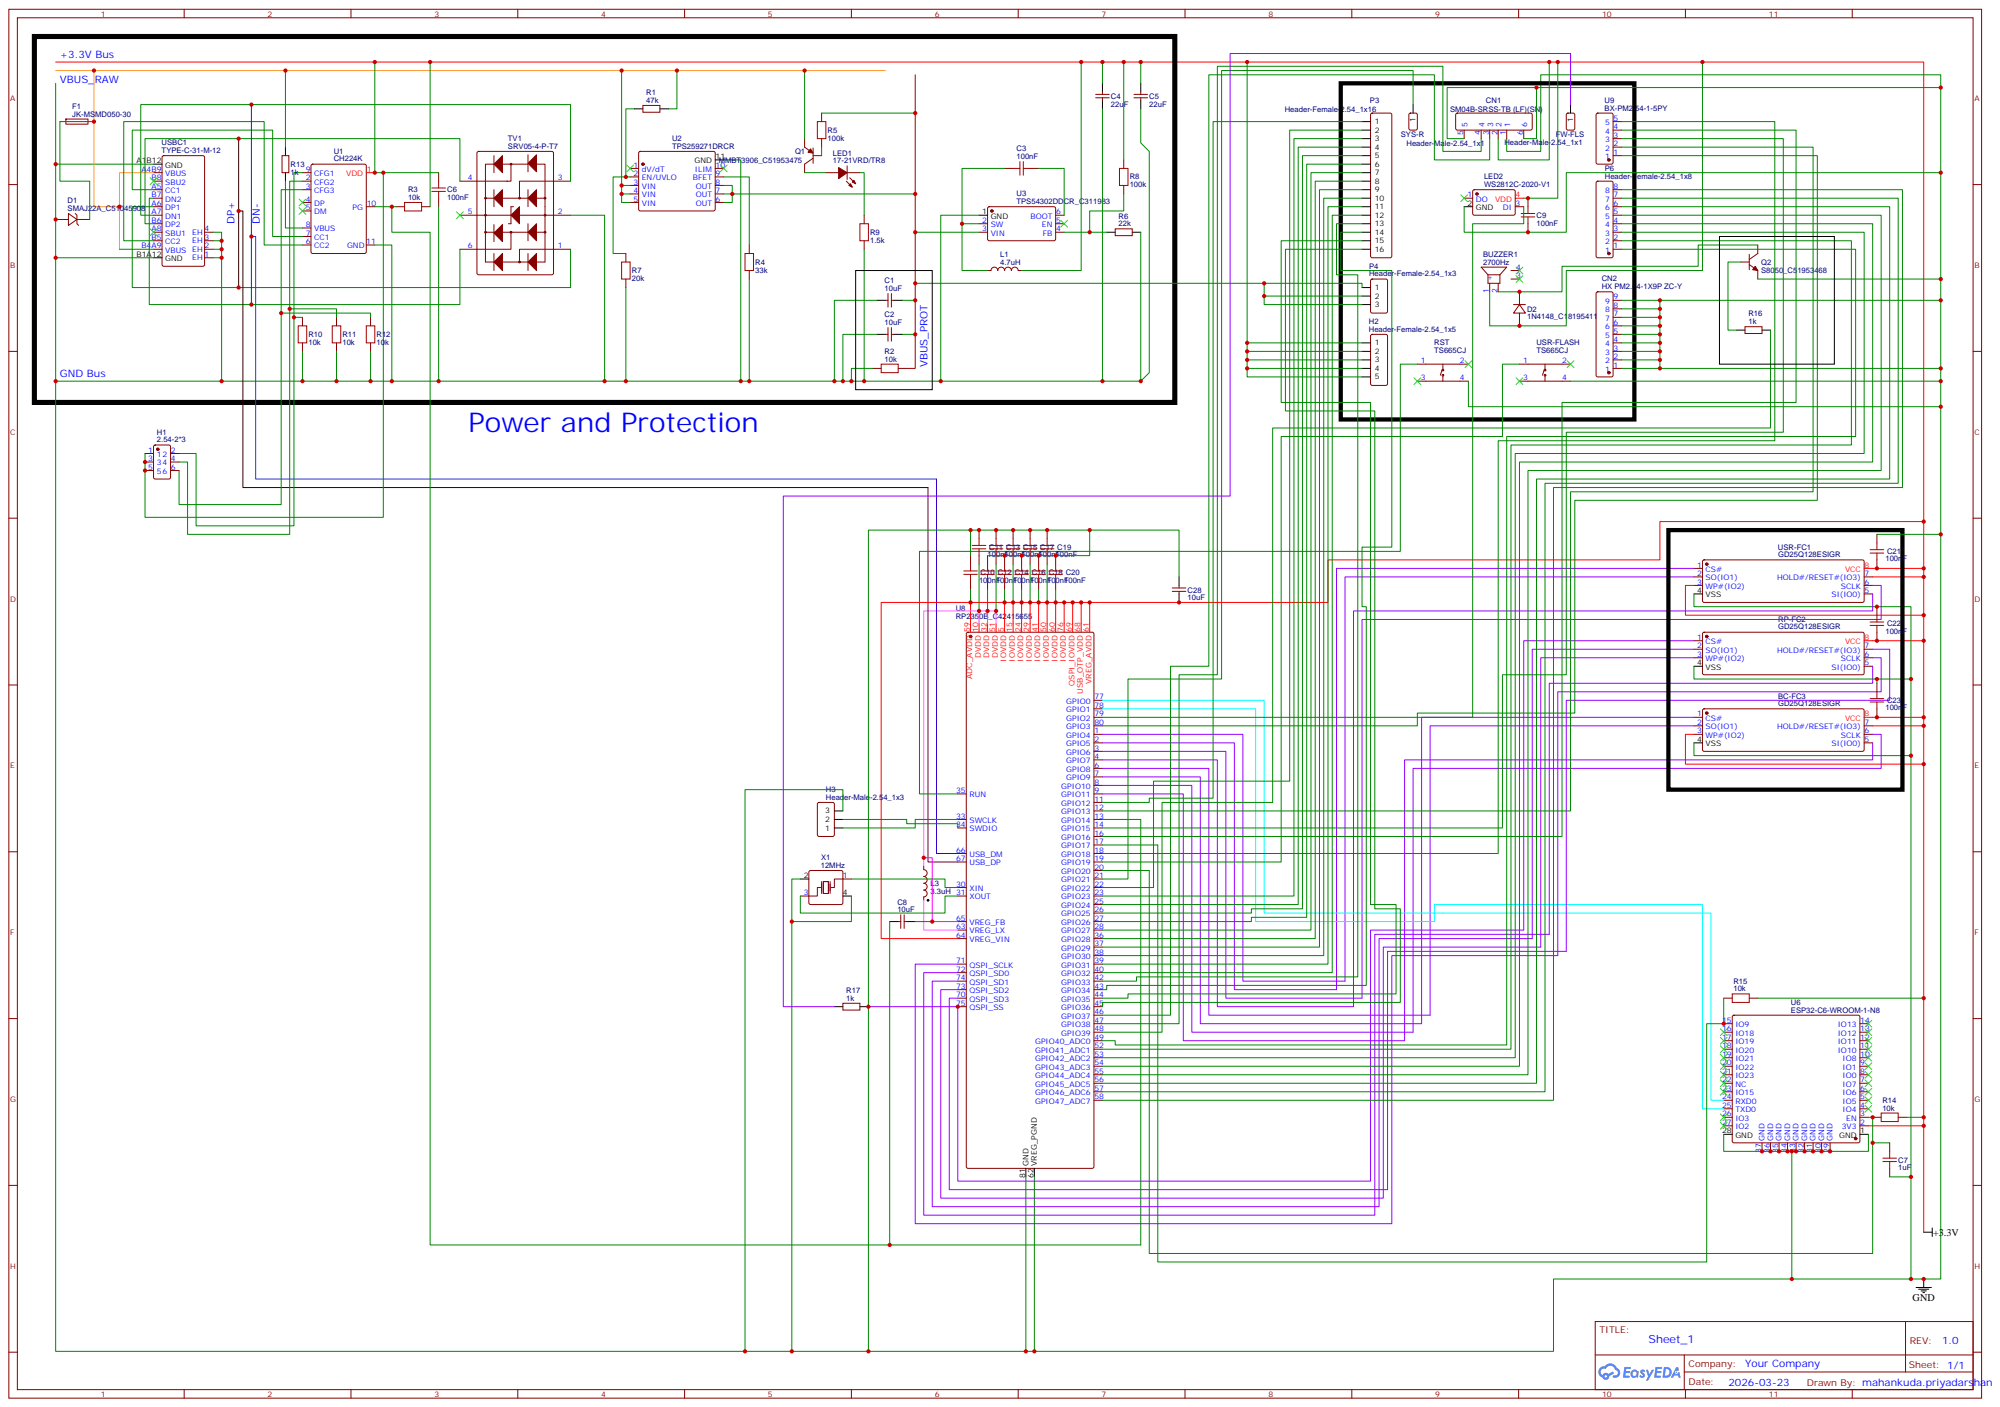
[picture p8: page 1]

SM04B-SRSS-TB (LF)(SN)

C11 C13 C15 C17 C19
100nF | 100nF | 100nF | 100nF

GND 29 GND 30 GND 31 GND 32 GND 33 GND 34 GND 35 GND 36 GND 37

Drawn By: mahankuda.priyadarshan

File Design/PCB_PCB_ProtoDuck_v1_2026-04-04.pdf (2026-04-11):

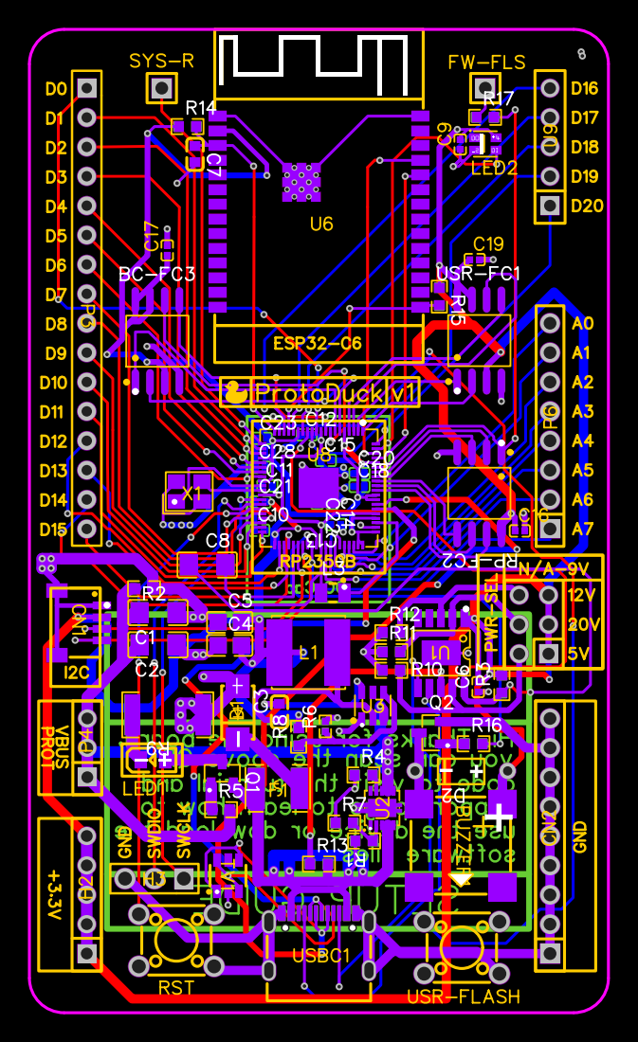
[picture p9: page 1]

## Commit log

2026-04-11 Initital commit: ProtoDuck Design and Architechture Documentation
    [BOM_ProtoDuck_v1_2026-04-04.csv, PickAndPlace_PCB_ProtoDuck_v1_2026-04-04.csv]
2026-05-04 Enhance README with detailed board specifications
    Expanded the README to include detailed descriptions of board features, system architecture, power protection, storage system, pinout, emergency recovery, and project links.
2026-05-04 PCB Design File
    [PCB_ProtoDuck_v1_2026-05-04.pcbdoc]
2026-05-17 BOM Upload
    [BOM_ProtoDuck_v1_2026-05-17.csv]
2026-05-17 Update BOM.csv with new component entries
    Updated BOM.csv to include new components and details.
    [BOM.csv, BOM_ProtoDuck_v1_2026-05-17.csv]
